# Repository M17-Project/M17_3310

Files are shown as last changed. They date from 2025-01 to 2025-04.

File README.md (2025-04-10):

# M17_3310
Mainboard replacement for the Nokia 3310/3330.

> [!CAUTION]
> The board's thickness is 1.0mm. Anything thicker **will not** fit.

## Original mainboard photos
Both photos in the `misc` directory are cropped, so that if you scale them for 108mm height, you should be able to make direct measurements using GIMP or other image editing software.

## SA868S UHF module firmware
The RF module should be flashed with [OpenRTX](https://github.com/OpenRTX/sa8x8-fw). The instructions on how to do that are in the readme, see the [*Firmware Flashing*](https://github.com/OpenRTX/sa8x8-fw?tab=readme-ov-file#firmware-flashing) section for details. The RF module can be flashed before, or after soldering it in place.

> [!NOTE]
> The device will appear frozen if the firmware running on the RF module is not OpenRTX.

## Device firmware
See the example firmware [here](https://github.com/M17-Project/M17_3310-fw).

### Flashing over USB
1. Plug in the USB cable.
2. Press and hold the *OK* button (large horizontal one with a blue bar, just below the display).
3. Press the power button at the top of the device.
4. Release the *OK* button.

The device should enter USB DFU mode and should be recognized by CubeProgrammer.

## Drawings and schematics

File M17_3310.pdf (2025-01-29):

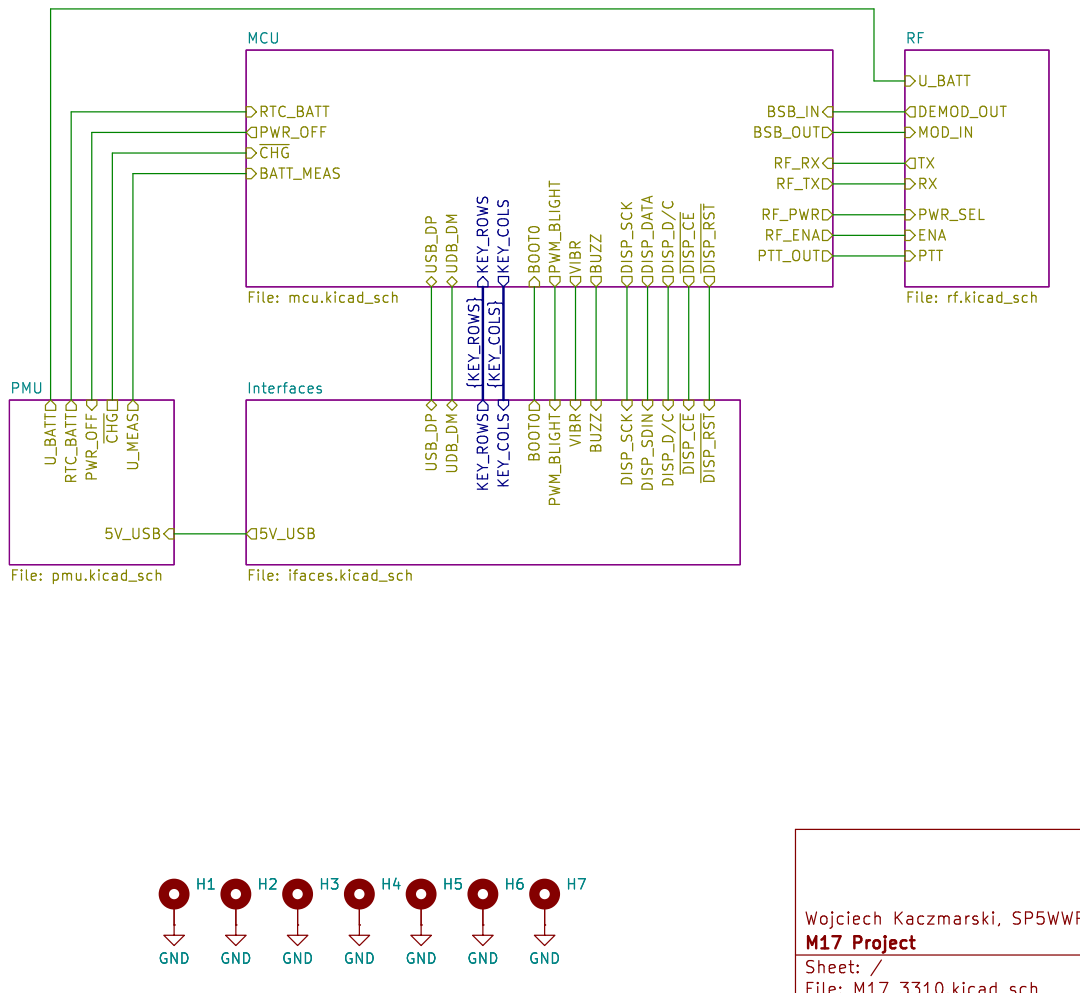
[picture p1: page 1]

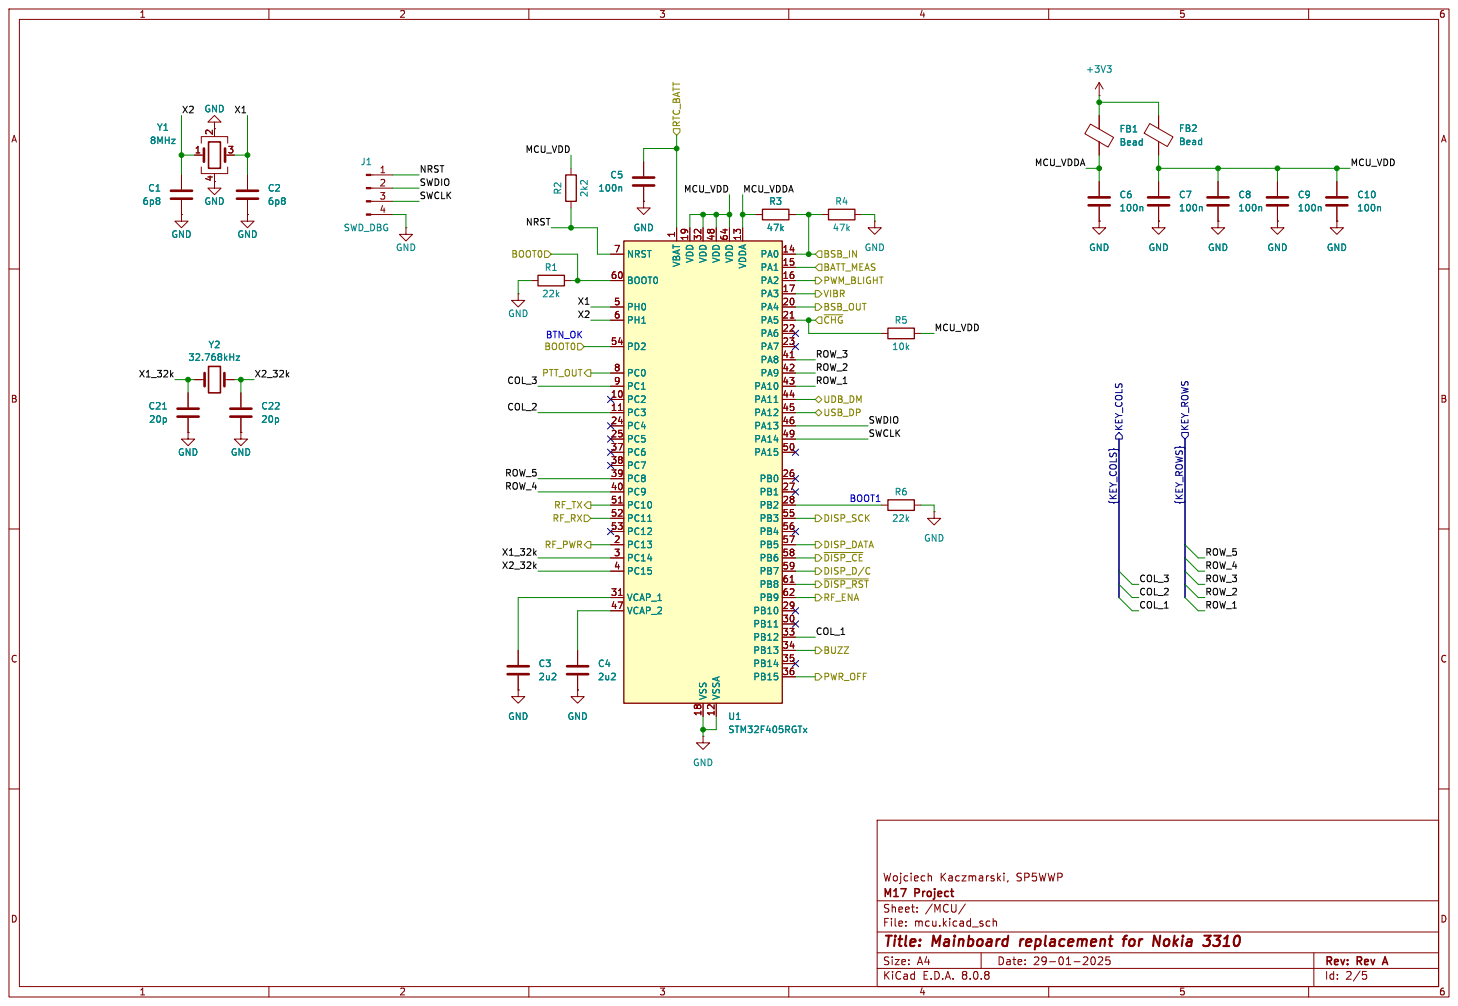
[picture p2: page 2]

1 PC2 10 PC3 11 VSSA 12 VDDA 13 PA0 14 PA1 15 PA2 16 PA3 17 VSS 18 VDD 19 PC13 2 PA4 20 PA5 21 PA6 22 PA7 23 PC4 24 PC5 25 PB0 26 PB1 27 PB2 28 PB10 29 PC14 3 PB11 30 VCAP_1 31 VDD 32 PB12 33 PB13 34 PB14 35 PB15 36 PC6 37 PC7 38 PC8 39 PC15 4 PC9 40 PA8 41 PA9 42 PA10 43 PA11 44 PA12 45 PA13 46 VCAP_2 47 VDD 48 PA14 49 PH0 5 PA15 50 PC10 51 PC11 52 PC12 53 PD2 54 PB3 55 PB4 56 PB5 57 PB6 58 PB7 59 PH1 6 BOOT0 60 PB8 61 PB9 62 VDD 64 NRST 7 PC0 8 PC1 9 C21

1 PC2 10 PC3 11 VSSA 12 VDDA 13 PA0 14 PA1 15 PA2 16 PA3 17 VSS 18 VDD 19 PC13 2 PA4 20 PA5 21 PA6 22 PA7 23 PC4 24 PC5 25 PB0 26 PB1 27 PB2 28 PB10 29 PC14 3 PB11 30 VCAP_1 31 VDD 32 PB12 33 PB13 34 PB14 35 PB15 36 PC6 37 PC7 38 PC8 39 PC15 4 PC9 40 PA8 41 PA9 42 PA10 43 PA11 44 PA12 45 PA13 46 VCAP_2 47 VDD 48 PA14 49 PH0 5 PA15 50 PC10 51 PC11 52 PC12 53 PD2 54 PB3 55 PB4 56 PB5 57 PB6 58 PB7 59 PH1 6 BOOT0 60 PB8 61 PB9 62 VDD 64 NRST 7 PC0 8 PC1 9 U1STM32F405RGTx GND

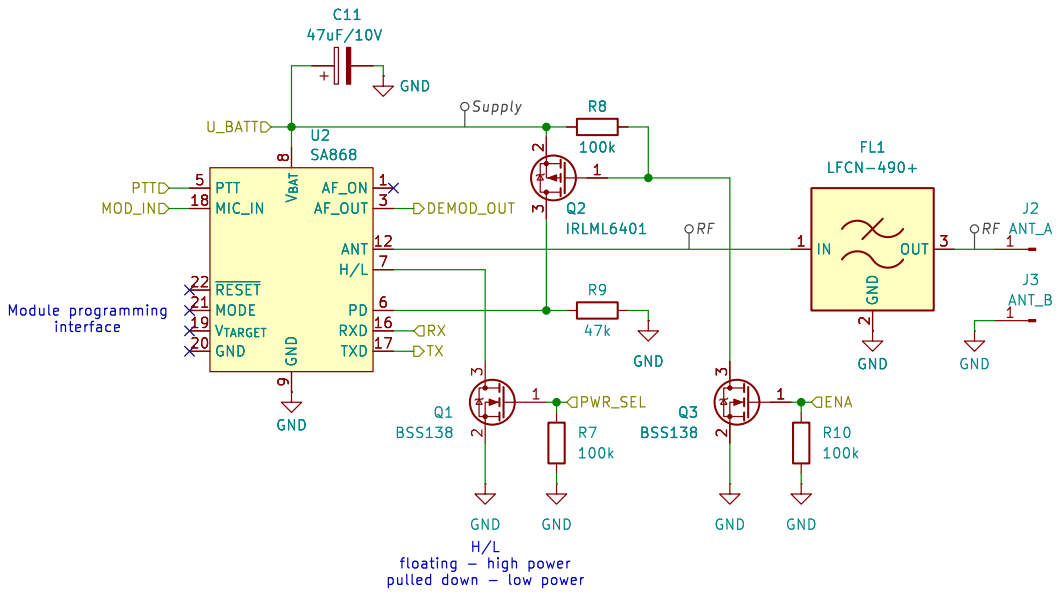
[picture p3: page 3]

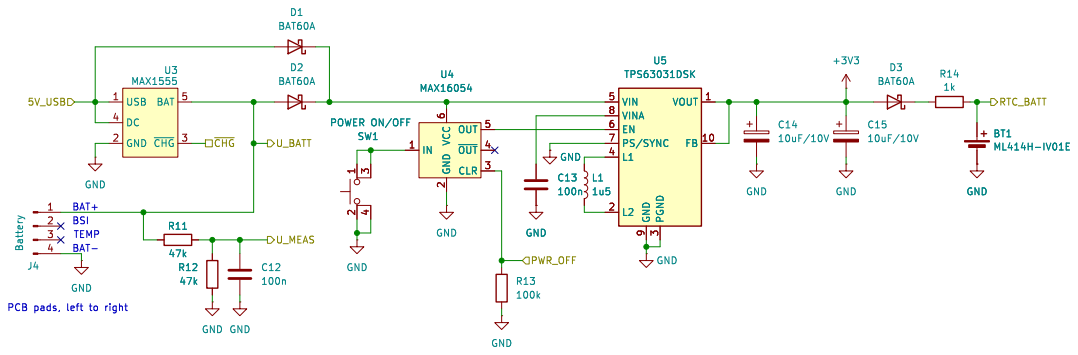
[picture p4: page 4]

3 4 SW1 POWER ON/OFF GND GND

2 CLR 3 ~{OUT}4 OUT 5 VCC

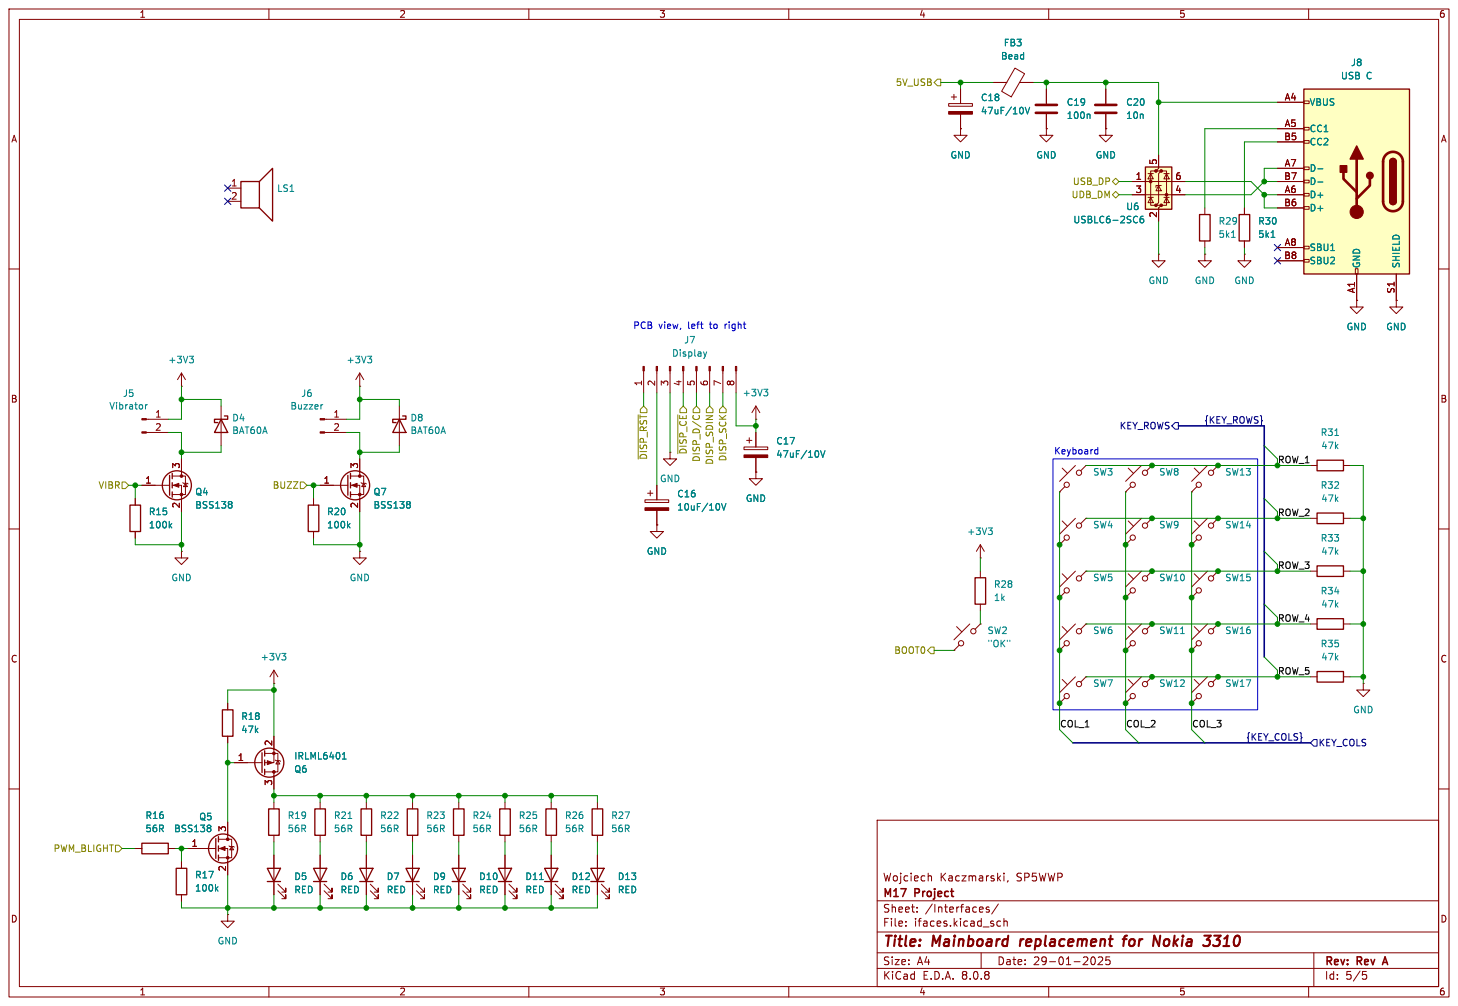
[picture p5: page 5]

{KEY_COLS} PCB view, left to right

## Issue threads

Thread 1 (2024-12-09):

Too large ferrite beads

sp5wwp, 2024-12-09:
Parts `FB1`, `FB2`, and `FB3` (`NFZ2MSD102SZ10L`) are too big, 0806, but the footprint is 0603.

Fix: keep the footprints and replace the beads with smaller ones.

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

sp5wwp, 2025-01-24:
The footprints were 0805.

Issue fixed in [f80ed89](https://github.com/M17-Project/M17_3310/commit/f80ed8938d63d0415eb90267c8950fa36e2ab9c7).

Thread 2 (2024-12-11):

RTC resonator caps might be required

sp5wwp, 2024-12-11:
Test the RTC, and if proves to be unstable or inaccurate, add a pair of capacitors.

sp5wwp, 2025-01-24:
Fixed in [f80ed89](https://github.com/M17-Project/M17_3310/commit/f80ed8938d63d0415eb90267c8950fa36e2ab9c7).

Closed 2025-01-24.

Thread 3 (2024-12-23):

TPS63031 might not work properly under light loads

sp5wwp, 2024-12-23:
It might be required to pull the `PS/SYNC` pin low.

sp5wwp, 2025-01-29:
Pulling `PS/SYNC` pin down greatly improves efficiency at light loads.

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

sp5wwp, 2025-01-29:
Fixed in [51de6ee](https://github.com/M17-Project/M17_3310/commit/51de6ee9882c8314751f6f3e096e9efc2b78bd92).

Closed 2025-01-29.

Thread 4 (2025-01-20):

USB-C receptacle position

sp5wwp, 2025-01-20:
USB-C receptacle might be placed too deep in the chassis.

sp5wwp, 2025-01-24:
Fixed in [f80ed89](https://github.com/M17-Project/M17_3310/commit/f80ed8938d63d0415eb90267c8950fa36e2ab9c7).

Closed 2025-01-24.

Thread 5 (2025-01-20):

RF module too high

sp5wwp, 2025-01-20:
SA868S RF module doesn't fit the chassis.

Fix: add a rectangular hole in the PCB for the module, re-route a bunch of signals. This should give an extra 1mm of margin.

sp5wwp, 2025-01-20:
Temporary workaround: cut away a piece of the plastic chassis right at the bottom of the battery compartment.

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

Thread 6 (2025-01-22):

Get rid of the MAX16054

sp5wwp, 2025-01-22:
The chip is completely unnecessary. STM32 can run in low-power mode and be woken up using an external trigger (key press). There's no need for an expensive power switch.

sp5wwp, 2025-07-01:
The button itself *is* necessary, it's the MAX16054 that is expensive and might be replaced with something else or removed completely, having the button routed directly to the MCU.

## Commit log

2025-01-24 fixes
    - USB-C closer to the board's edge
    - added 20pF caps for the 32.768kHz resonator
    - replaced ferrite beads with 0805-sized ones
    [M17_3310.kicad_sch, ifaces.kicad_sch, mcu.kicad_sch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]
2025-01-29 `PS/SYNC` tied to GND
    [M17_3310.kicad_sch, ifaces.kicad_sch, mcu.kicad_sch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]
2025-02-10 alternative SA868 footprint
2025-02-24 bumped kicad to 9.0.0
    [M17_3310.kicad_sch, ifaces.kicad_sch, mcu.kicad_sch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]
2025-03-25 Update README.md
    added a warning related to the board's thickness
2025-04-28 bumped kicad to 9.0.1
